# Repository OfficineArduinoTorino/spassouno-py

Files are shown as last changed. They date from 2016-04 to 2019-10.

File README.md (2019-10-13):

# (S)passoUno

Uno speciale tavolo da riprese per creare cortometraggi animati con la tecnica dell’animazione stop-motion.

## Interfaccia e comandi

### Tastiera
Di seguito i comandi che possono essere utilizzati da tastiera:

| TASTIERA | FUNZIONE | GPIO RASPBERRY PI | UI |
|--- | --- | --- | --- |
SPACE_KEY | Take a snapshot | GPIO 2 | Big Red Button
DOWN_KEY | Accelerate preview | GPIO 4 | Pink Button
UP_KEY | Decelerate preview | GPIO 3 | Yellow Button
D_KEY | Delete session (new session) | NC | NC
X_KEY | Delete a frame | GPIO 27 | Black Button
M_KEY | Make video | GPIO 17 | Green Button
G_KEY | Make animated GIF (not implemented) | NC | NC
Q_KEY | Quit | NC | NC
F_KEY | Toggle fullscreen | NC | NC
PLUS_KEY | Zoom preview in | NC | NC
MIN_KEY | Zoom preview out | NC | NC

### Setup (S)passouno Singolo

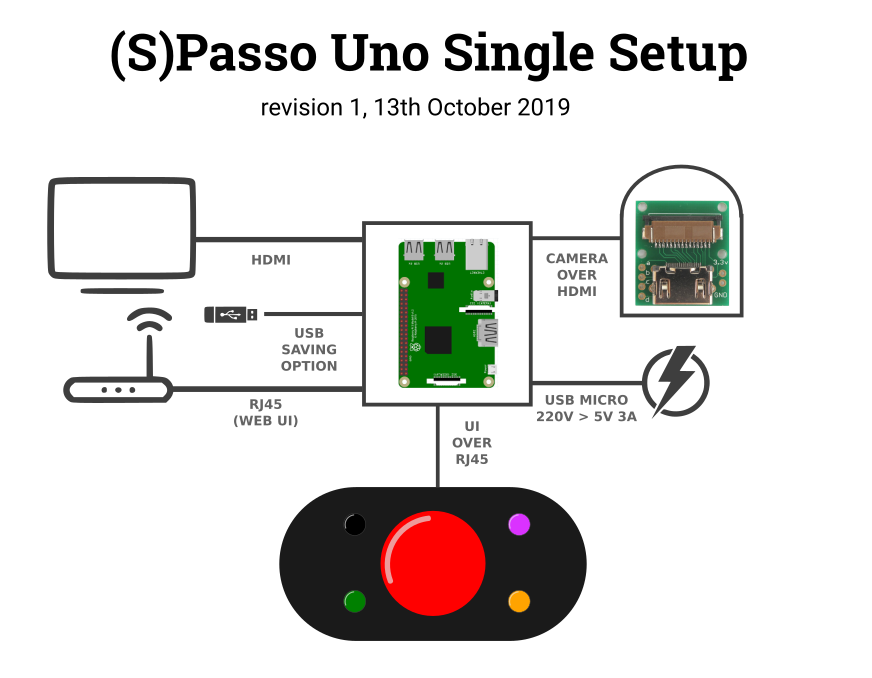
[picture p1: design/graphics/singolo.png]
Spasso Uno Singolo


### Setup (S)passouno Piovra Mode (Maker Faire Rome 2019)

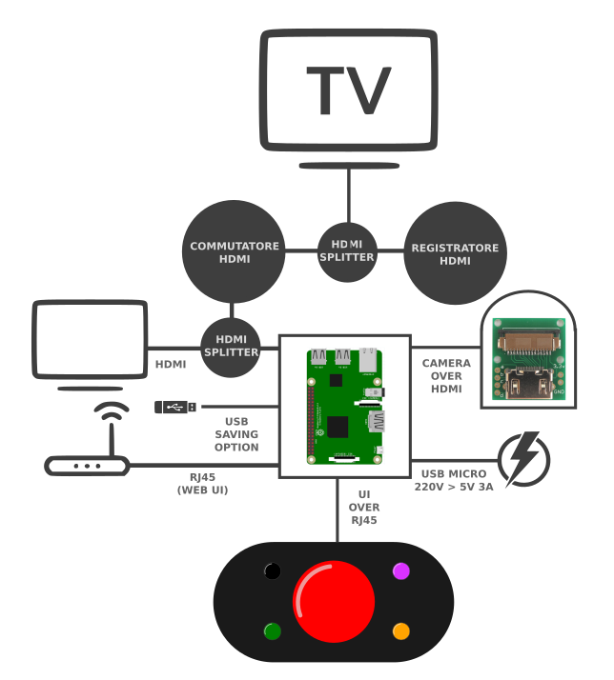
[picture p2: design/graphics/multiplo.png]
Spasso Uno Multiplo


### RJ45 Pin Mapping

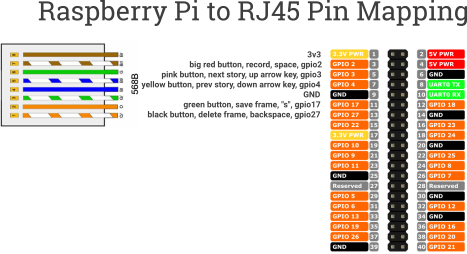
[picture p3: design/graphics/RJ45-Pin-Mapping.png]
RJ45 Pin Mapping


Design: [Design folder](https://github.com/OfficineArduinoTorino/spassouno-py/tree/master/design)

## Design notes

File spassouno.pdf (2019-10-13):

## Spassouno Installation Manual

Officine Innesto

October 31, 2018

## 1 Installation and Setup

1.1 Materials

- Raspberry Pi (1,2,3 A/A+/B/B+)
- Camera (Raspberry Official or Linux Compatible USB)
- Spassouno Controller

1.2 Download an flash DietPi

Get a micro SD card with a minimum size of 4 GB (Class 10 UHS-I, A1 Recommended) and format it. Download the DietPi image from the official website. (https://dietpi.com/)
Use Etcher or any method you prefer to flash the previously downloaded image to the microSD. It will take a couple of minutes to finish.
When it is done, plug it into the Raspberry Pi and connect the network cable (if you prefer, plug monitor, keyboard and mouse).

1.3 First Boot

At the first boot, the DietPi image will resize the filesystem and do some updates. Then it will display the login prompt (root/dietpi).
After you logged in, you have to change your password (spassouno); then you will be asked to do the first config via Dietpi-Software utility. Here you have to install LXDE (Graphical Environment), WiFi Hotspot, ProFTP (lightweight FTP server), Samba (Windows File Sharing Server) that you can find under DietPi-Optimized menu.
Next, select Git from the DietPi-Additional menu, choose OpenSSH as SSH server (as it enables scp commands) and Samba under File Server. Then click install, it will take quite some time to do all the stuff and also some reboots.
If you are configuring via SSH, the SHA key will change so you have to remove it from the known list and redo the matching (the terminal prompt will suggest what to do).
Open dietpi-config and enable the camera module under Display Options, if you are using a MIPI-CSI camera (Raspberry Official one); then reboot.
Now you are ready to install Spassouno software.

1.4 Installation

First, you have to install all the software dependencies that the software needs to work correctly.

$ sudo apt install python-pip python-dev python-setuptools
$ sudo apt install libjpeg8-dev libgstreamermm-1.0-dev python-pygame
$ sudo apt install lighttpd libwebp-dev imagemagick zlib1g-dev

1

$ sudo apt install libtiff5-dev libjpeg-dev libfreetype6-dev liblcms2-dev $ sudo apt install gstreamer1.0-plugins-base gstreamer1.0-omx libav-tools $ sudo apt install libjpeg62-turbo-dev gstreamer1.0-plugins-good
$ sudo apt install gstreamer1.0-tools gstreamer1.0-plugins-bad usbmount $ sudo apt install zlibc build-essential tcl8.6-dev tk8.6-dev python-tk
$ sudo pip install setuptools pillow picamera

After the process is finished, change your working directory to /opt and clone the GitHub repository. (https://github.com/OfficineArduinoTorino/spassouno-py) Then open the folder of the repository and run python spassouno.py, in a few seconds the display will load the home screen and you can start using it.

1.5 Add features

Features that are nice to have are a shutdown button and autostart of the python script. For the shutdown, open /DietPi/config.txt in your favourite editor and add

dtoverlay=gpio-shutdown

To make the script start at boot, you can use cron or init.d. In the GitHub folder there is a script for cron, you can set it up with the next commands. Digit crontab -e to edit the cron file then add at the end of the file @reboot sh /opt/spassouno-py/startspasso.sh, save it and then digit the following commands:

$ sudo chmod +x /opt/spassouno-py/startspasso.sh
$ sudo systemctl enable cron

If you want to add WiFi Hotspot capabilities, under dietpi-config network settings you can set your ssid and password (SpassoUno-HotSpot / SpassoDue) then copy the config/www folder under /var. This folder contains all the webserver files. Change your directory to /var/www and then digit:

$ sudo ln -s /opt/spassouno-py/images/export ./download

This way all the videos exported will be available for download. For the FTP and Samba (windows) Shares change your directory to /opt/spassouno-py/config and digit

$ cp ./proftpd.conf /etc/proftpd/
$ cp ./smb.conf /etc/samba/

Then reboot. This will add anonymous access to the images folder.

Last Revisioned by Alberto Perro - 30/10/18 a.perro@officine.cc

2

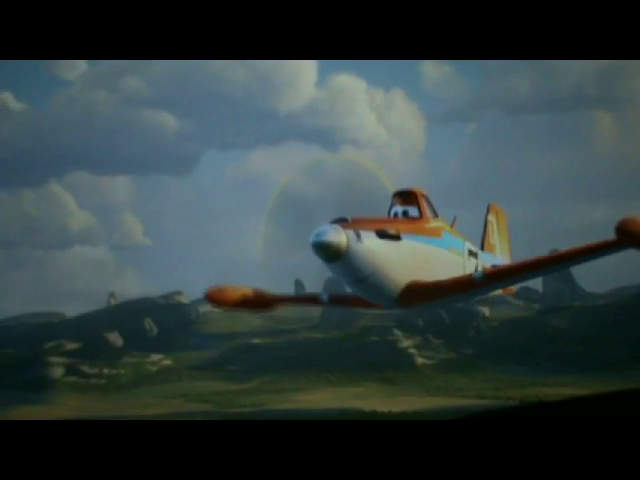
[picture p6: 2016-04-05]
res/frame.png

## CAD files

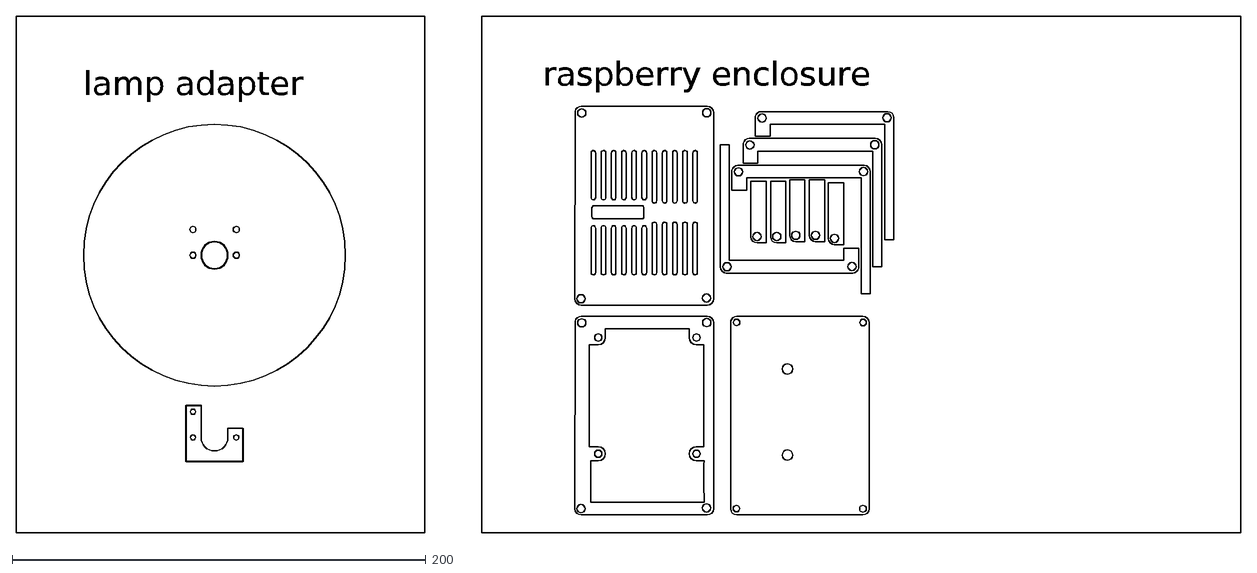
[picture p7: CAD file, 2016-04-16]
design/ENCLOSURE RASPBERRY+LAMPADAPTER.dxf
lamp adapter
raspberry enclosure

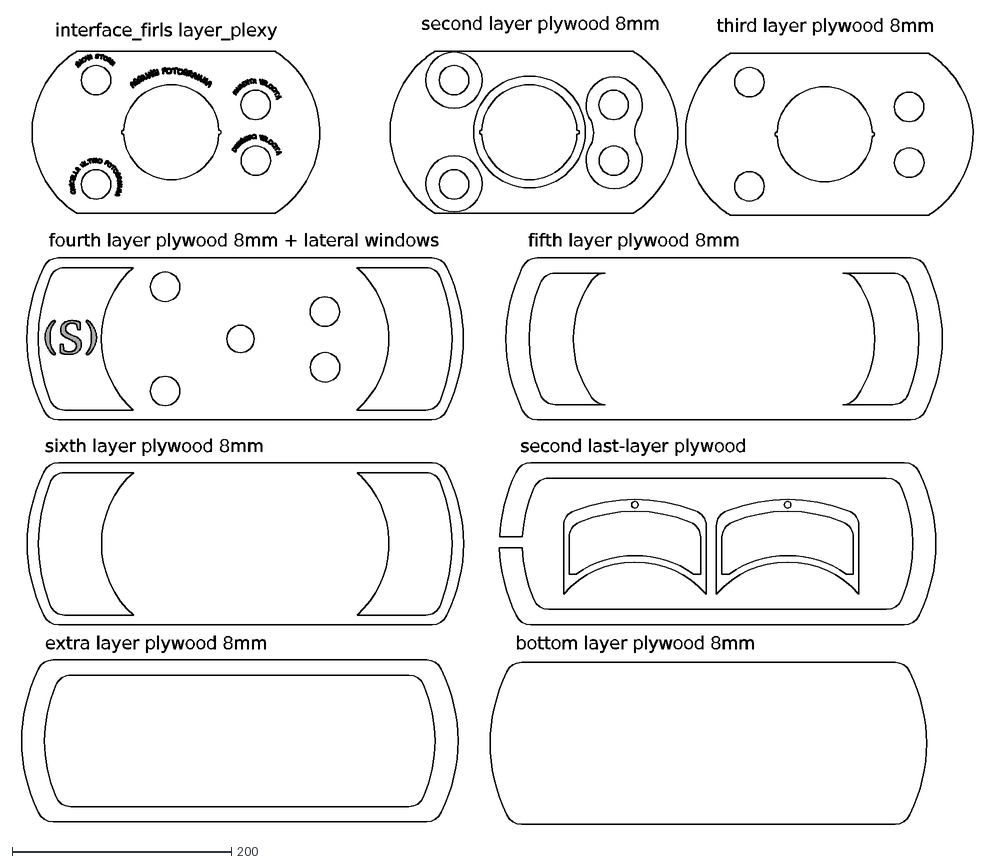
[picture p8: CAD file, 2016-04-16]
design/spasso1_controler.dxf
interface_firls layer_plexy
second layer plywood 8mm
third layer plywood 8mm
fourth layer plywood 8mm + lateral windows
fifth layer plywood 8mm
sixth layer plywood 8mm
second last-layer plywood
bottom layer plywood 8mm
extra layer plywood 8mm

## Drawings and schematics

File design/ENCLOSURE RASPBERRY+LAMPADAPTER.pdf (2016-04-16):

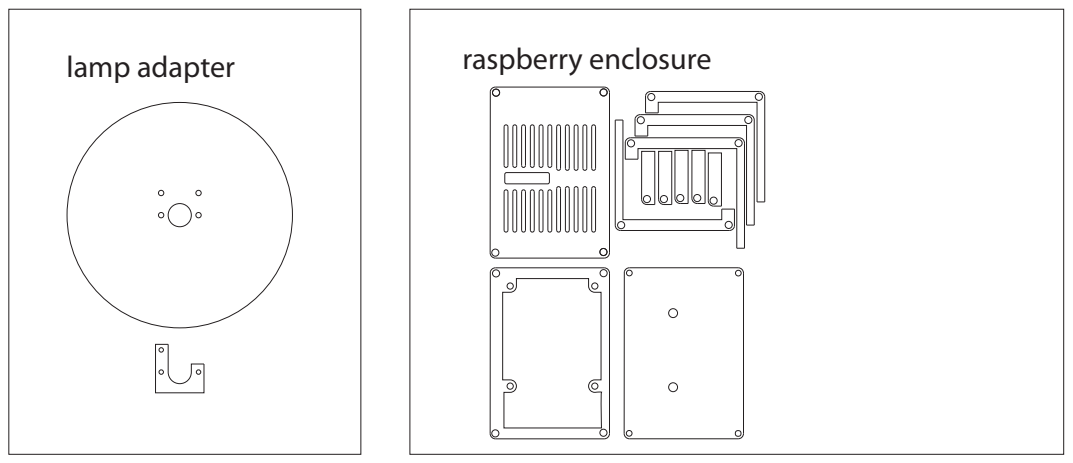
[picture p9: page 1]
lamp adapter; raspberry enclosure

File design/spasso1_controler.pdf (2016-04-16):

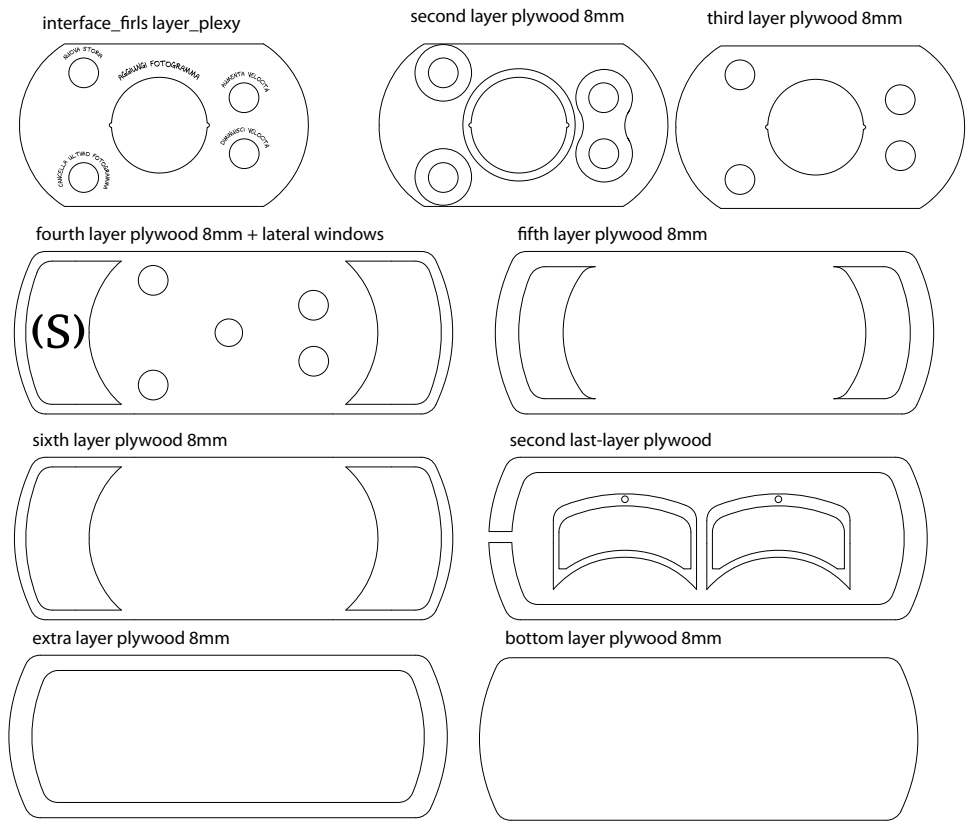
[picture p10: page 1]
interface_rls layer_plexy; second layer plywood 8mm; third layer plywood 8mm; fourth layer plywood 8mm + lateral windows; fth layer plywood 8mm; sixth layer plywood 8mm; second last-layer plywood; extra layer plywood 8mm; bottom layer plywood 8mm

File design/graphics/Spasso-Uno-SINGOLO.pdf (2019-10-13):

# (S)Passo Uno Single Setup

# revision 1, 13th October 2019

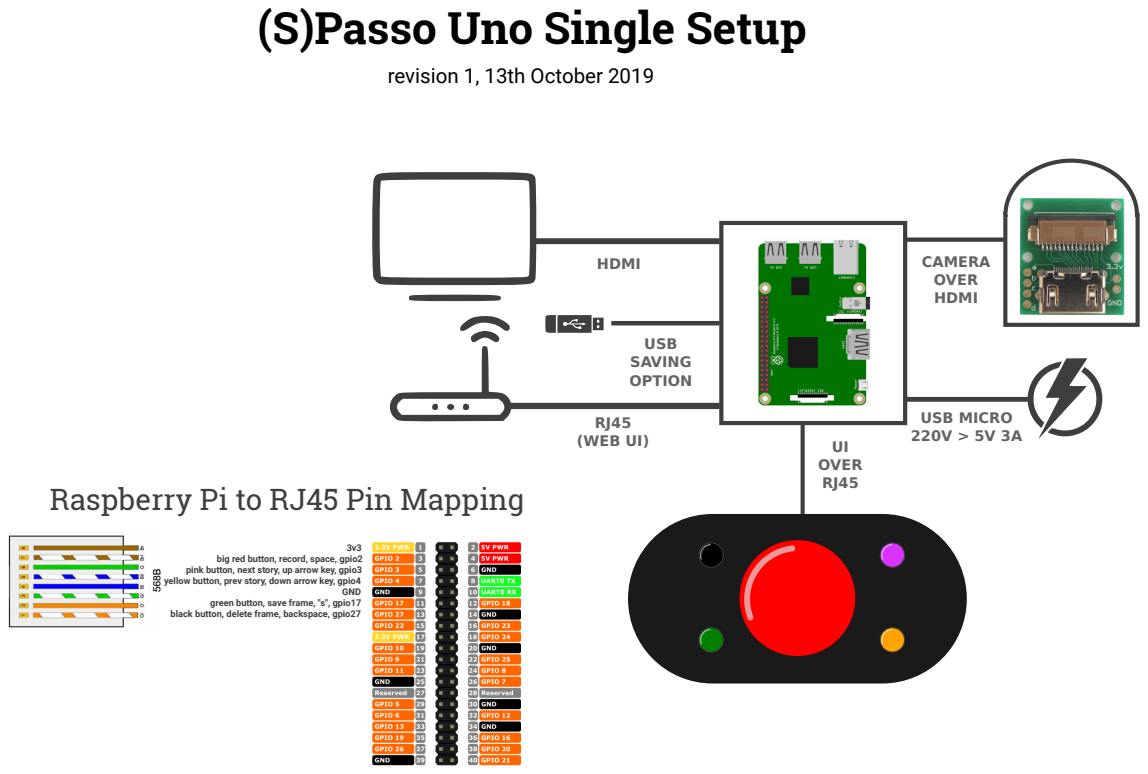
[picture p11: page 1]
UI OVER RJ45; CAMERA OVER HDMI; HDMI; RJ45 (WEB UI); USB MICRO 220V > 5V 3A; USB SAVING OPTION; GND

Raspberry Pi to RJ45 Pin Mapping

big red button, record, space, gpio2
pink button, next story, up arrow key, gpio3
yellow button, prev story, down arrow key, gpio4

green button, save frame, "s", gpio17

black button, delete frame, backspace, gpio27

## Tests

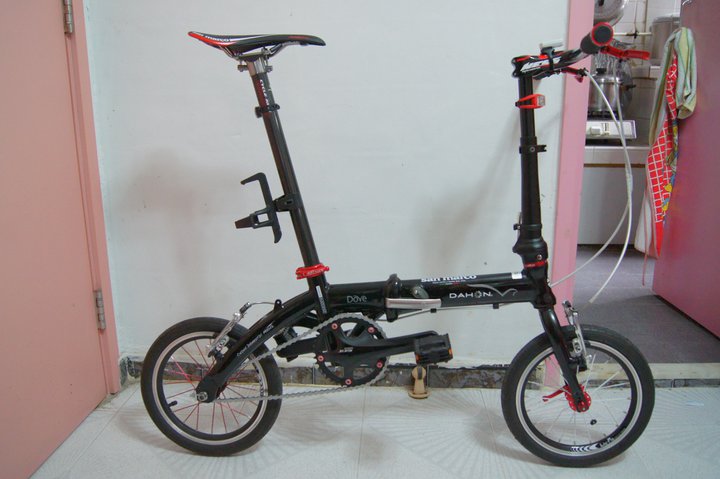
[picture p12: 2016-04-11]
res/testImg/dove1.jpg

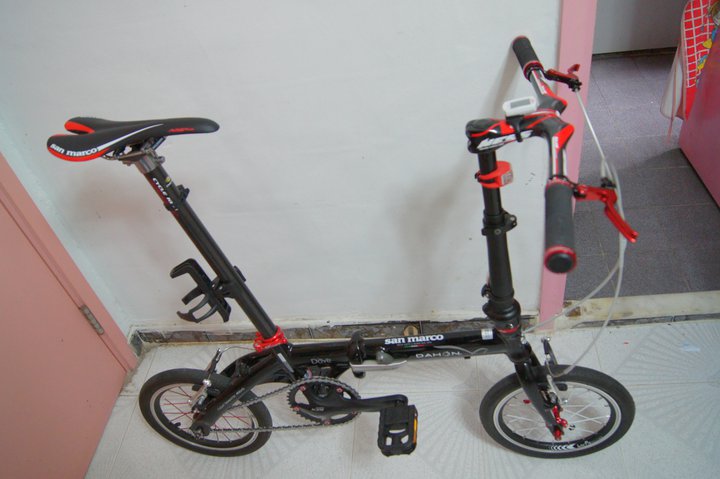
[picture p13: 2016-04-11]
res/testImg/dove2.jpg

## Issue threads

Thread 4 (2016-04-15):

Non far ripartire dal frame 1 la sequenza ad ogni pressione

vongomben, 2016-04-15:
Ciao.
E' possibile non resettare la riproduzione dei frame all'aggiunta di un nuovo fotogramma?
A livello di UX é più interessante se la sequenza continua e come ultimo fotogramma si veda quello che é stato appena aggiunto.

Ho cercato di guardare il codice ma purtroppo non ci capisco molto :(

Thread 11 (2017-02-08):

Proporzione delle due finestre coerente

vongomben, 2017-02-08:
Al momento le due finestre non sono proporzionate: la prima é 4:3, la seconda anche, ma sono un pezzo é visibile da interfaccia. Sarebbe opportuno renderle coerenti e della stessa dimensione.

Closed 2017-02-20.

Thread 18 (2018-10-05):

Can't save to usb

albydnc, 2018-10-05:
`root@spassouno:/opt/spassouno-py# python spassouno.py

<Surface(1920x1080x32 SW)>

Setting pipeline to PAUSED ...

Pipeline is PREROLLING ...

Pipeline is PREROLLED ...

Setting pipeline to PLAYING ...

New clock: GstSystemClock

Got EOS from element "pipeline0".

Execution ended after 0:00:04.113395519

Setting pipeline to PAUSED ...

Setting pipeline to READY ...

Setting pipeline to NULL ...

Freeing pipeline ...
`

albydnc, 2018-10-05:
I suggest to change the export command from gstlaunch to ffmpeg

albydnc, 2018-10-15:
the issue was usbmount, not mounting usb drives. resolved by using direct mount and umount of /dev/sda1

Closed 2018-10-15.

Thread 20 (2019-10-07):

Making the controller remote

vongomben, 2019-10-07:
The controller (Pushbutton) should be remote, wireless.

[Gianfranco Caputo](http://archive.fabacademy.org/fabacademy2016/fablabtorino/students/440/exercises/W15/net.html) made an interesting PCB for sending very simple data using [nRF24L01](http://www.nordicsemi.com/eng/nordic/download_resource/8041/1/24073600) radio signal.

I'd rather prefer using [this chinese solution](Aukru 3X Wireless 433 MHz RF), ora adding it to GIanfranco's board.

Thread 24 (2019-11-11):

pdf guide

nikyred78, 2019-11-11:
Hello,

I have followed yours step but I need just one more information. Is not really clear the following command: "After the process is finished, change your working directory to /opt and clone the GitHub
repository". Can you please explain better this step or send me some gude?Thanks in advance

albydnc, 2019-11-12:
Hi, thanks for opening this issue!
After you install all the requirements, change the directory using `cd /opt` and do `git clone https://github.com/OfficineArduinoTorino/spassouno-py.git`

nikyred78, 2019-11-12:
Hi,
Thanks for your info. I will try this operation.

nikyred78, 2019-11-13:
Hi albydnc,
I tried this command "cd /opt and do git clone https://github.com/OfficineArduinoTorino/spassouno-py.git" but the terminal tells me : command not found.
Why this? Thanks

nikyred78, 2019-11-16:
I have resolved with the download “git” . On pdf there is no writing.

vongomben, 2019-11-16:
We have to review the Readme and update the guide.
Which is your setup? Is it working?

nikyred78, 2019-11-16:
Ciao , ti scrivo in italiano perché ti ho conosciuto al Make feire di Roma.non so se ti ricordi ma ti avevo chiesto di questo progetto. Comunque ho seguito la guida alla lettera , tutto ok fino a quando servirebbe l’installazione di git ma nella guida non è riportata. Sono all’inizio delle prove, l’interfaccia la visualizzo ma non riesco a far funzionare il pulsante, io porto il GND con l’ingresso GPIO non so se devo dare il 3,3

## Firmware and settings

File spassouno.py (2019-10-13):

import random
import pygame
from camera import Camera
from frame_manager import FrameManager
import testi
from pygame.locals import *
import time
import os


IS_RASPBERRY=True
pi=None
try:
    import pigpio
except:
	IS_RASPBERRY=False

if IS_RASPBERRY:
	pi = pigpio.pi()
	pi.set_mode(2, pigpio.INPUT)
	pi.set_mode(3, pigpio.INPUT)
	pi.set_mode(4, pigpio.INPUT)
	pi.set_mode(17, pigpio.INPUT)
	pi.set_mode(27, pigpio.INPUT)
	#set pulldown resistors
	pi.write(2, 0)
	pi.write(3, 0)
	pi.write(4, 0)
	pi.write(17, 0)
	pi.write(27, 0)
	hardware_keys={}
	hardware_space=False;#gpio2
	hardware_up=False;#gpio3
	hardware_down=False;#gpio4
	hardware_save=False;#gpio17
	hardware_delete=False;#gpio27
	

def check_hardware_buttons():
	global pi,last_time_text,hardware_space,hardware_up,hardware_down,hardware_save,hardware_delete,current_text_tag,NEXT_CRITICAL_ACTION
	if pi.read(2)==1:
		if not hardware_space:
			camera.save_frame(frameManager)
			current_text_tag="scattato"
			last_time_text=time.time()
			hardware_space=True
	else:
		hardware_space=False
	
	if pi.read(3)==1:
		if not hardware_up:
			NEXT_CRITICAL_ACTION="changetosession"+str(frameManager.current_session+1)
			current_text_tag="cambio sessione"
			last_time_text=time.time()
			hardware_up=True
	else:
		hardware_up=False

	if pi.read(4)==1:
		if not hardware_down:
			NEXT_CRITICAL_ACTION="changetosession"+str(frameManager.current_session-1)
			current_text_tag="cambio sessione"
			last_time_text=time.time()
			hardware_down=True
	else:
		hardware_down=False

	if pi.read(17)==1:
		if not hardware_save:
			NEXT_CRITICAL_ACTION="save"
			current_text_tag="saving"
			last_time_text=time.time()
			hardware_save=True
	else:
		hardware_save=False

	if pi.read(27)==1:
		if not hardware_delete:
			frameManager.remove_frame()
			current_text_tag="rimosso"
			last_time_text=time.time()
			hardware_delete=True
	else:
		hardware_delete=False


def keyboard_interaction():
	global current_text_tag,last_time_text,animation_speed,NEXT_CRITICAL_ACTION
	if IS_RASPBERRY:
		check_hardware_buttons()
	for event in pygame.event.get():
			if event.type == pygame.KEYDOWN:
				if event.key == pygame.K_ESCAPE:
					pygame.quit()
					exit()
				elif event.key == pygame.K_SPACE:
					camera.save_frame(frameManager)
					current_text_tag="scattato"
				elif event.key == pygame.K_UP:
					NEXT_CRITICAL_ACTION="changetosession"+str(frameManager.current_session+1)
					current_text_tag="cambio sessione"
				elif event.key == pygame.K_DOWN:
					NEXT_CRITICAL_ACTION="changetosession"+str(frameManager.current_session-1)
					current_text_tag="cambio sessione"
				elif event.key == pygame.K_x:
					frameManager.remove_frame()
					current_text_tag="rimosso"
				elif event.key == pygame.K_s:
					NEXT_CRITICAL_ACTION="save"
					current_text_tag="saving"
				elif event.key == pygame.K_r:
					camera.ruota()
				elif event.key == pygame.K_DELETE:
					frameManager.delete_all()
				elif event.key == pygame.K_BACKSPACE:
					frameManager.delete_current_scene()
				elif event.key == pygame.K_p:
					animation_speed/=2.0
					if animation_speed<0.003125:
						animation_speed=0.003125
				elif event.key == pygame.K_o:
					animation_speed*=2.0
					if animation_speed>3.2:
						animation_speed=3.2
				else:
					for n in range(10):
						if event.key == pygame.__dict__["K_"+str(n)]:
							nf=n-1
							if nf<0:
								nf=9
							NEXT_CRITICAL_ACTION="changetosession"+str(nf)
							current_text_tag="cambio sessione"
				last_time_text=time.time()


def critical_action_manager():
	global NEXT_CRITICAL_ACTION,current_text_tag
	if NEXT_CRITICAL_ACTION=="save":
		ok=frameManager.save(animation_speed)
		if ok:
			current_text_tag="salvato"
		else:
			current_text_tag="no usb"

	for n in range(frameManager.number_of_sessions):
		if NEXT_CRITICAL_ACTION=="changetosession"+str(n):
			frameManager.load_session(n)
			current_text_tag="sessione cambiata"

	NEXT_CRITICAL_ACTION=None




pygame.init()
infoObject = pygame.display.Info()
display=pygame.display.set_mode((infoObject.current_w, infoObject.current_h),pygame.FULLSCREEN)
#display = pygame.display.set_mode((1680,1050),pygame.FULLSCREEN)
#display = pygame.display.set_mode((640,480),pygame.FULLSCREEN)

pygame.mouse.set_visible(False)

frame=pygame.surface.Surface((display.get_width()/2,display.get_height()/2), 0, display)

logo=pygame.image.load(os.path.join(os.path.dirname(os.path.realpath(__file__)),"logoSpassoUno.jpeg"))
logo=pygame.transform.scale(logo,(display.get_width()/8,int(display.get_height()/7.5)))

camera=Camera((1920,1080),display)
frameManager=FrameManager()

last_time=time.time()
last_time_text=time.time()
animation_speed=0.1
#used to write warning text before doing operations that freeze the software
NEXT_CRITICAL_ACTION=None

current_text_tag="tutorial"

image=camera.frame
print image

testi.load_text_it(frameManager,display.get_width())

if camera.is_picamera:
	y=display.get_height()/4
	camera.camera.start_preview(fullscreen=False,window=(0,y,display.get_width()/2,display.get_height()/2))

def draw_frame_position(pos,width):
	if len(frameManager.images)==0:
		step_pos=pos[0]
	else:
		step_pos=pos[0]+(width*frameManager.current_frame)/len(frameManager.images)
	
	pygame.draw.line(display, (255,255,255), (pos[0],pos[1]-20), (pos[0],pos[1]+20))
	pygame.draw.line(display, (255,255,255), (pos[0]+width,pos[1]-20), (pos[0]+width,pos[1]+20))
	pygame.draw.line(display, (255,255,255), (pos[0],pos[1]), (pos[0]+width,pos[1]))
	pygame.draw.line(display, (255,0,0), (step_pos,pos[1]-20), (step_pos,pos[1]+20), 3)
	
def draw_text():
	global current_text_tag
	
	if time.time()-last_time_text>10.0:
		current_text_tag="tutorial"
		
	testi.draw(display,current_text_tag,(display.get_width()/2,(display.get_height()*7)/8),horiz="center",vert="center")

while True:
	keyboard_interaction()

	display.fill((0,0,0))

	display.blit(logo,((display.get_width()-logo.get_width())/2,5))

	if not camera.is_picamera:
		if camera.camera.query_image():
			image = camera.camera.get_image(camera.frame)

	aspect_ratio=float(image.get_width())/image.get_height()

	image=pygame.transform.scale(image, (display.get_width()/2, int((display.get_width()/2)/aspect_ratio)))
	display.blit(image,(0,(display.get_height()-image.get_height())/2))

	if time.time()-last_time>animation_speed:
		last_time=time.time()
		frame=frameManager.get_next_frame()
		if frame == None:
			frame=pygame.surface.Surface((display.get_width()/2,display.get_height()/2), 0, display)
		else:
			frame=pygame.transform.scale(frame, (display.get_width()/2, int((display.get_width()/2)/aspect_ratio)))
	
	display.blit(frame,(display.get_width()/2,(display.get_height()-frame.get_height())/2))

	#display current session number
	testi.draw(display,"session"+str(frameManager.current_session),(display.get_width()-10,20),horiz="right")
	#display current frame number
	draw_frame_position((display.get_width()/2,display.get_height()/5),display.get_width()/2-10)
	#display current text:
	draw_text()
	
	pygame.display.update()

	critical_action_manager()



pygame.quit()
if camera.is_picamera:
	camera.camera.stop_preview()

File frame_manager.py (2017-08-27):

import random
import pygame
import os
class FrameManager():
	def __init__(self):
		self.number_of_sessions=10
		self.current_session=0
		self.current_frame=0
		self.path=os.path.join(os.path.dirname(os.path.realpath(__file__)),"images")
		self.images=[]
		if not os.path.isdir(self.path):
			os.makedirs(self.path)
		for i in range(self.number_of_sessions):
			p=os.path.join(self.path,str(i))
			if not os.path.isdir(p):
				os.makedirs(p)

		self.load_session(self.current_session)

	def get_current_session_path(self):
		return os.path.join(self.path,str(self.current_session))

	def save_image(self,image):
		filename=os.path.join(self.get_current_session_path(),"frame_"+"0"*(5-len(str(len(self.images))))+str(len(self.images))+".jpeg")
		pygame.image.save(image,filename)
		image=pygame.image.load(filename)
		self.images.append(image)

	def load_session(self,number):
		if number>=self.number_of_sessions:
			number=0
		if number < 0:
			number=self.number_of_sessions-1
		self.current_session=number
		files=[f for f in os.listdir(self.get_current_session_path()) if os.path.isfile(os.path.join(self.get_current_session_path(), f))]
		files.sort()
		
		self.images=[]
		for f in files:
			self.images.append(pygame.image.load(os.path.join(self.get_current_session_path(), f)))

		self.current_frame=len(self.images)-1

	def get_next_frame(self):
		if len(self.images)==0:
			return None
		self.current_frame+=1
		if self.current_frame>=len(self.images):
			self.current_frame=0
		return self.images[self.current_frame]

	def remove_frame(self):
		if len(self.images)==0:
			return

		self.images=self.images[0:-1]
		files=[f for f in os.listdir(self.get_current_session_path()) if os.path.isfile(os.path.join(self.get_current_session_path(), f))]
		files.sort()
		os.remove(os.path.join(self.get_current_session_path(),files[-1]))

	def delete_current_scene(self):
		self.images=[]
		files=[f for f in os.listdir(self.get_current_session_path()) if os.path.isfile(os.path.join(self.get_current_session_path(), f))]
		for f in files:
			os.remove(os.path.join(self.get_current_session_path(),f))

	def delete_all(self):
		self.images=[]
		for s in range(self.number_of_sessions):
			self.current_session=s
			self.delete_current_scene()
		self.current_session=0

	def save(self,frate):
		if len(self.images)==0:
			return
			
		if self.is_usb_plugged():
			path = self.get_current_session_path()
			#os.system("convert -delay 20 -loop 0 "+path+"/*.jpeg /media/usb0/movie"+str(self.current_session)+".mpeg")
			#os.system("gst-launch-1.0 multifilesrc location="+path+"/frame_%05d.jpeg index=0 caps=\"image/jpeg,framerate=24/1\" ! jpegdec ! omxh264enc ! avimux ! filesink location=/media/usb0/movie"+str(self.current_session)+".avi")
			framerate=int(1.0/frate)
			os.system("gst-launch-1.0 multifilesrc location="+path+"/frame_%05d.jpeg ! \"image/jpeg,framerate="+str(framerate)+"/1\" ! jpegparse ! jpegdec ! omxh264enc ! avimux ! filesink location=/media/usb0/movie"+str(self.current_session)+".avi")
			#os.system("gst-launch-1.0 multifilesrc location="+path+"/frame_%05d.jpeg ! \ caps=\"image/jpeg,framerate=1/"+str(frate)+",pixel-aspect-ratio=1/1\" ! jpegdec ! ffmpegcolorspace ! video/x-raw-yuv,format=(fourcc)l420 ! theoraenc ! oggmux ! filesink location=/media/usb0/movie"+str(self.current_session)+".ogg")
			#os.system("gst-launch-1.0 multifilesrc location="+path+"/frame_%05d.jpeg index=0 caps=\"image/jpeg,framerate=24/1\" ! jpegdec ! omxh264enc ! avimux ! filesink location=timelapse.avi")
		else:
			print "please Insert USB Drive and Retry"
			return False
		return True

	def is_usb_plugged(self):
		partitionsFile = open("/proc/partitions")
		lines = partitionsFile.readlines()[2:]#Skips the header lines
		for line in lines:
			words = [x.strip() for x in line.split()]
			minorNumber = int(words[1])
			deviceName = words[3]
			if minorNumber % 16 == 0:
				path = "/sys/class/block/" + deviceName
				if os.path.islink(path):
					if os.path.realpath(path).find("/usb") > 0:
						#return "/dev/%s" % deviceName
						return True
		return False

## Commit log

2016-04-11 Verbose logging and fix frame order
    [spassouno.py]
2016-04-11 Added remove of last frame
2016-04-11 Frame order patch
2016-04-12 caricato sketch arduino per interfaccia
2016-04-15 aggiornato il .ino
2016-04-15 arduinoSpassoUno.ino fine tuning
2016-04-16 Design by Fabrizio Alesso
    [ENCLOSURE RASPBERRY+LAMPADAPTER.dxf, spasso1_controler.dxf]
2017-02-08 added gif and avi exports to USB external device
2017-02-08 gif and mp4 bugFix
    [spassouno.py]
2017-05-08 buttons implemented on raspberry
2017-05-09 implementato autoavvio su raspberry
2017-08-27 fixed save to usb issue on raspberry
    [camera.py, frame_manager.py, spassouno.py]
